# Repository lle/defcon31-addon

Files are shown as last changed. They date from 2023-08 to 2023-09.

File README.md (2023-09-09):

# DEFCON31 BLINKY BADGE-ADDON
This project recycles the same schematic and foundation code from my Snake Business Card. The main difference is that there is only a single button on the PCB that the user can interact with. In the development of this project, STM32 CubeMX and CubeIDE were used to configure and generate the HAL (hardware-abstraction-layer). Some says I'm cheating and using a code generator. I don't disagree XD.

To edit/compile/flash the code you only need to install CubeIDE. Although feel free to use any tools you like. 
You can download CubeIDE here: https://www.st.com/en/development-tools/stm32cubeide.html

## Code and Game Behavior
The badge-addon is loaded with a set of animation. The animation is selected in the main loop in "main.c". There is a switch statement that cycles between each animation. When the button is pressed, the animation is incremented to select a new one. Each animation is described in a specific .c/.h file
* anim_name.c 
* anim_random.c
* anim_swipe.c

You can add additional animation by adding a new .c/.h pair. Add an #include in main.c and call the your animation function in the switch statement.

## About the Timer16
The clock is set to 8Mhz and the timer16 counter is set to 1000 (see "tim.c"). Thus 8Mhz/1000=8Khz.
The timer runs at 8khz. It updates a new LED 8000 cycles per second. 

### Analogy
Imagine there is a cursor that is moving left to right, top to bottom. Every cycle, the cursor moves to the next LED, reads the buffer and decides if the LED should be on/off. In other words, it takes 64 cycles to update the full screen since there is 64 LEDs. Consequently, it takes 8000Hz/64LEDs = 125ms to update the full screen.

### Where is the timer handler?
The timer handler function "HAL_TIM_PeriodElapsedCallback()" is called in the file "stm32f0xx_it.c". At that location the "screen_interruptUpdate()" function is called to update the next LED.

## About LED Matrix
The chip we are using is the STM32F0. The datasheet indicates that the maximum current through a whole GPIO PORT is 30mA. The LEDs are running at 20mA with the chosen current limit resistor. Therefore, the code is set to only turn on 1 single LED at a time in order to satisfy that requirement. Since the whole screen is updated every 125ms, there is enough persistence of vision to produce a consistent animation.

The low-level function which controls the individual LEDs is located in "ledHandler.c". The function 
"matrix_setLed_on()" is used to enable an LED. It can be seen that at the beginning of it, it calls "matrix_setLed_allOff()" to disable any previous LEDs and ensure the PORT never source more than 30mA.

## About screenBuffer.c
The screenBuffer is how you interact with the LED matrix. There is 1 main fundamental fonction you need:
* screen_set_bit(row, column, state)

This is function set the state of each LEDs in the 8x8 matrix. It's either 1 (on) or 0 (off).

Additionally, there are helper functions to make animating easier:
* screen_get_bit()
* screen_fill()	
* screen_clear()

## How to Flash
Things you need:
* ST-Link - I personally use an STM32F0 Nucleo Board: [497-15096-ND](https://www.digikey.ca/en/products/detail/stmicroelectronics/NUCLEO-F072RB/5047984)
* Female Connector: [H2193-ND](https://www.digikey.ca/en/products/detail/hirose-electric-co-ltd/DF13-4P-1-25DSA/241767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)
* Male Connector: [H2181-ND](https://www.digikey.ca/en/products/detail/hirose-electric-co-ltd/DF13-4S-1-25C/241750)
* Precrimped wires x4: [H4BXG-10112-B8-ND](https://www.digikey.ca/en/products/detail/hirose-electric-co-ltd/H4BXG-10112-B8/426117)

### Instruction
* Connect the ST-Link SWD header to the PCB's programming port
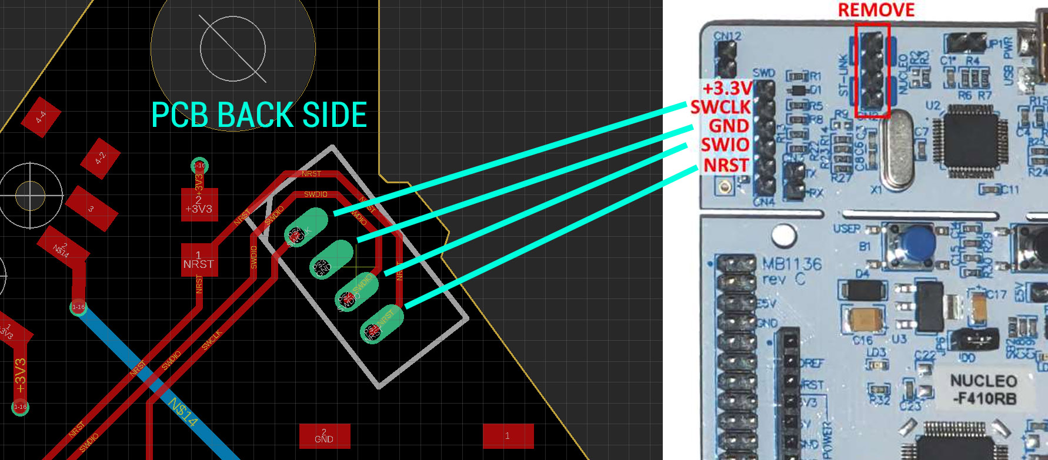
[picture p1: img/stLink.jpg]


* Compile the code in STM CubeIDE: "Project"->"Build All"
* Connect your Nucleo board to your computer
* Configure the debugger as follows: "Run" -> "Debug Configurations"
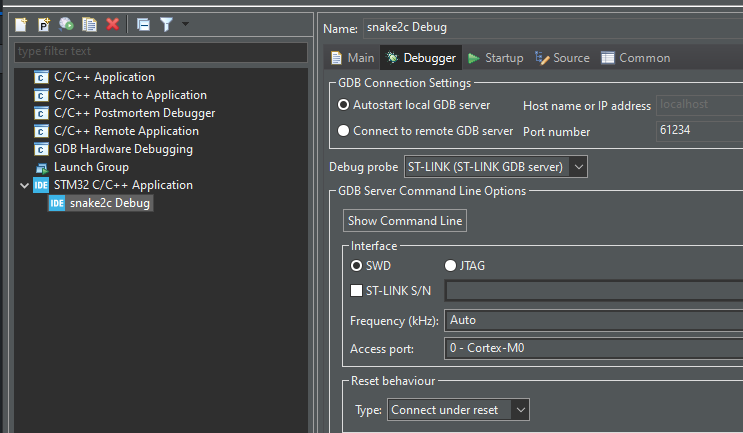
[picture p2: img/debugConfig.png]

* Flash the firmware: "Run" -> "Run"
* You will see this in the logs
```
Memory Programming ...
Opening and parsing file: ST-LINK_GDB_server_a15460.srec
  File          : ST-LINK_GDB_server_a15460.srec
  Size          : 21.34 KB 
  Address       : 0x08000000 
Erasing memory corresponding to segment 0:
Erasing internal memory sectors [0 21]
Download in Progress:
File download complete
Time elapsed during download operation: 00:00:01.454
Verifying ...
Download verified successfully 
Shutting down...
Exit.
```
* You might have to power cycle the PCB to get the firmware started the first time
* Congrats, you have flashed the addon. Happy coding.

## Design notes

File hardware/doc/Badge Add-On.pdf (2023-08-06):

Announcing…

## The Official DEF CON 31 Badge Customization Guide

(AKA the Non-Electronic Shitty Add-On Guide)
OK, but is it really a Shitty Add-On if the badge is non-electronic? Well, sort of!

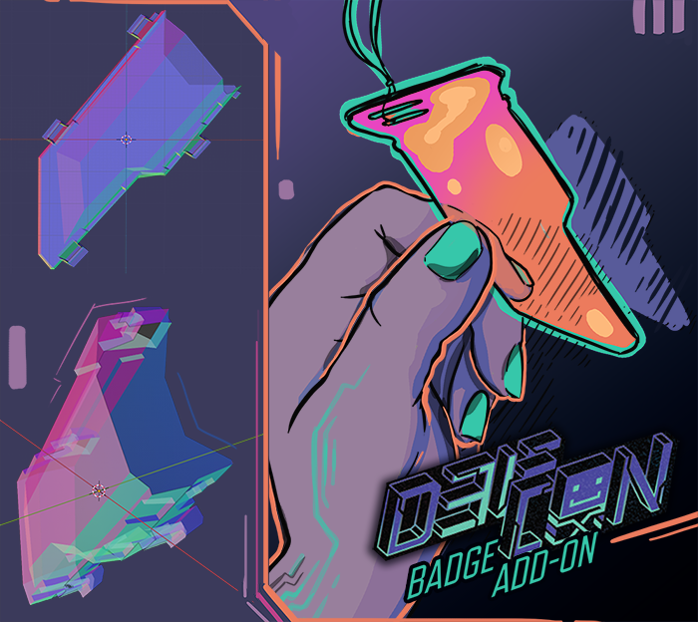
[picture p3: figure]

This year's badge is designed specifically to showcase customization. While I can't leak the whole badge, I can release the customizable portion of it.

The badge will include a small chamber, open at one end, with a transparent window facing outwards. What you put inside that chamber is entirely up to you. A PCB project, tiny snack dispenser, drawing of a cool bug... Whatever your skills and interests, you'll have some freedom to show them off.

### DETAILS:

Inside the chamber, you'll find a guide slot that runs down both sides, and is about 5mm deep. This allows an object equivalent to a thick card to slide in and out of the badge. Think PCB, laser cut acrylic, plastic card, cardboard, etc. You can totally fill the entire chamber up with pudding, and not use the guide slot at all, but for most projects, this should make things a little easier.

The inside of the chamber, from wall to wall, is 20mm at its thickest point. That means that if your project is a PCB, you'll still have space in front and back to accommodate, for example, smallish LEDs on front, and CR2032 holder and battery on back. BUT, be sure to check out the .blend file for what areas of the chamber are larger or smaller. The geometry is a little wild, and from where the card sits, the backside gives a little less room than the front.

Along the guide slot, you'll also see a couple small tab slots that should allow your project to snap in to place. I strongly recommend using a small secondary lanyard (wrist or keychain type), in addition to the tabs, to secure your project to your main lanyard, just in case. Card thicknesses will vary, and that means more wiggle for thinner materials. I can't promise that every project will stay in place while bopping around your neck at con with these specs, so please wear protection.

*Note - Inserts will be compatible with both human and inhuman badge types. Except for maybe UBER.

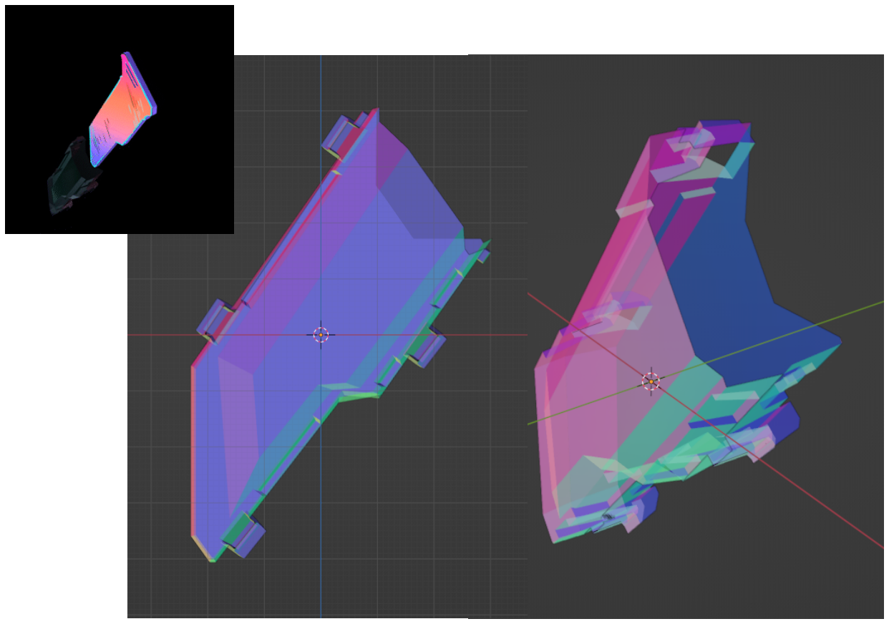
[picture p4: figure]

### BASIC MEASUREMENTS:

You’ll need to reference the .svg and .blend files for fit, but this should give you an idea of the space you’re working with.

Chamber Height: ~90mm (3.5”)
Chamber Width: ~30mm (1.2”)
Chamber Depth: ~20mm (.8”) at thickest point

Guide Slot: 5mm
Max Card Thickness for Guide Slot: 4.5mm
Min Card Thickness for Guide Slot: 1.5mm recommended (you can go thinner, but fit might get loose)

TIP: Design a small gap between measurements in the .blend file, and your project. Parts should be able to move freely without getting stuck.

A Note on Height - The chamber is wide open on one end, so you’re free to go taller, or have a ribbon cable or tentacle dangling out.

### FILES:

DC31BADGE-CARD-OUTLINE.svg
2D outline of an example insert shape, with cuts for lanyard
If you’re creating a flat object, this should be a good starting place

DC31BADGE-CHAMBER.blend
The inner geometry of the chamber, for more complex projects, so you know exactly how much space you’re working with

If you have questions, post them to the forums and I’ll do my best to answer them. Have fun, and I can’t wait to see what you create! <3
-Mar-

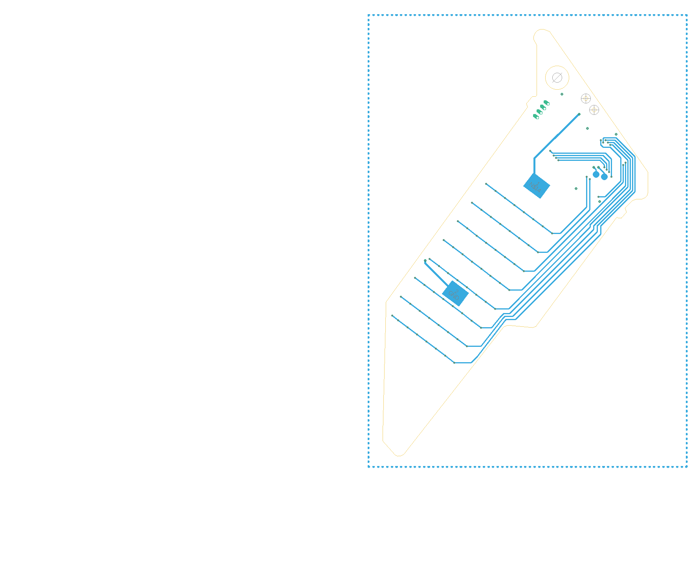
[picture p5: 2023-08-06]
hardware/gerber/pcb_bottom_copper.png

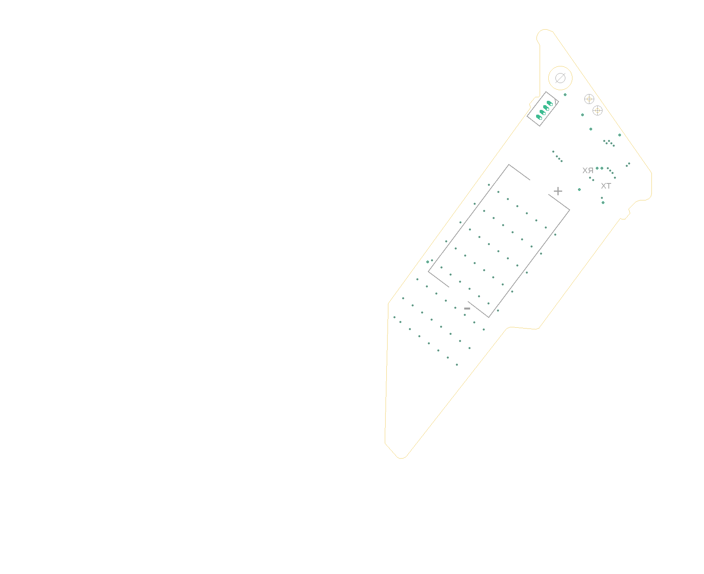
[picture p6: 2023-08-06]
hardware/gerber/pcb_bottom_silkscreen.png

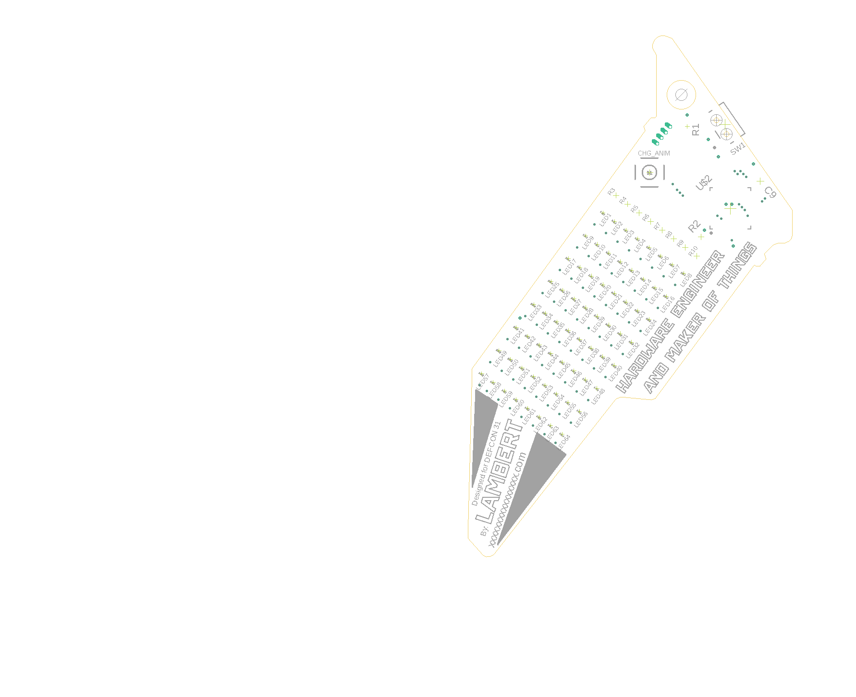
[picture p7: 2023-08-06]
hardware/gerber/pcb_top_silkscreen.png

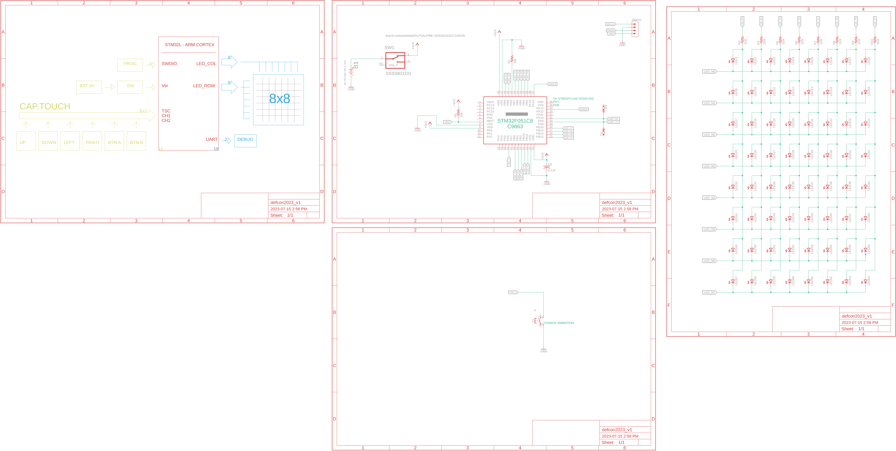
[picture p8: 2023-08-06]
hardware/gerber/schematic.png

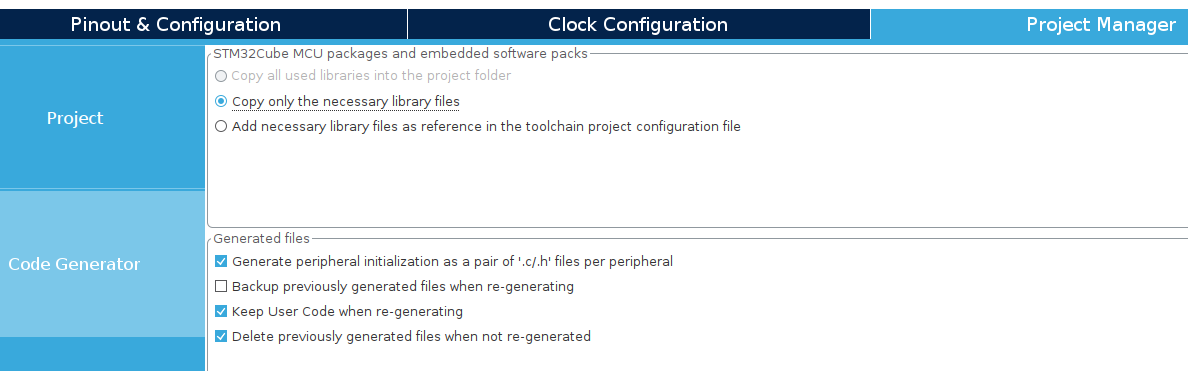
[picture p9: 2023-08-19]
img/cubeMX_codeGen.png

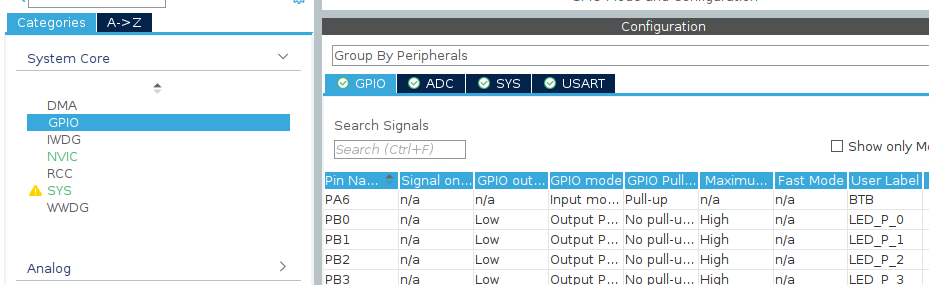
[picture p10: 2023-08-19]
img/cubeMX_gpio.png

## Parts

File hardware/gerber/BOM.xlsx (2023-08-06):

Comment | Footprint | Designator | JLCPCB ID | Digikey
 | CHIP-LED0603 | LED1 LED2 LED3 LED4 LED5 LED6 LED7 LED8 LED9 LED10 LED11 LED12 LED13 LED14 LED15 LED16 LED17 LED18 LED19 LED20 LED21 LED22 LED23 LED24 LED25 LED26 LED27 LED28 LED29 LED30 LED31 LED32 LED33 LED34 LED35 LED36 LED37 LED38 LED39 LED40 LED41 LED42 LED43 LED44 LED45 LED46 LED47 LED48 LED49 LED50 LED51 LED52 LED53 LED54 LED55 LED56 LED57 LED58 LED59 LED60 LED61 LED62 LED63 LED64 | C2286
 | TACTILE_SWITCH_SMD_5.2MM | S1 | C318884
0.1uF | C0603 | C9 | C14663
10k | R0603 | R1 R2 | C25804
110r | R0603 | R3 R4 R5 R6 R7 R8 R9 R10 | C173369
ALPS_SSSS811101ALPS_SSSS811101_0_0 | ALPS_SSSS811101_0 | SW1 | C109335
STM32L431CC | QFP50P900X900X160-48 | U$2 | C9863
Programmer Connector | 4pin 1.25mm | prog |  | H2193-ND

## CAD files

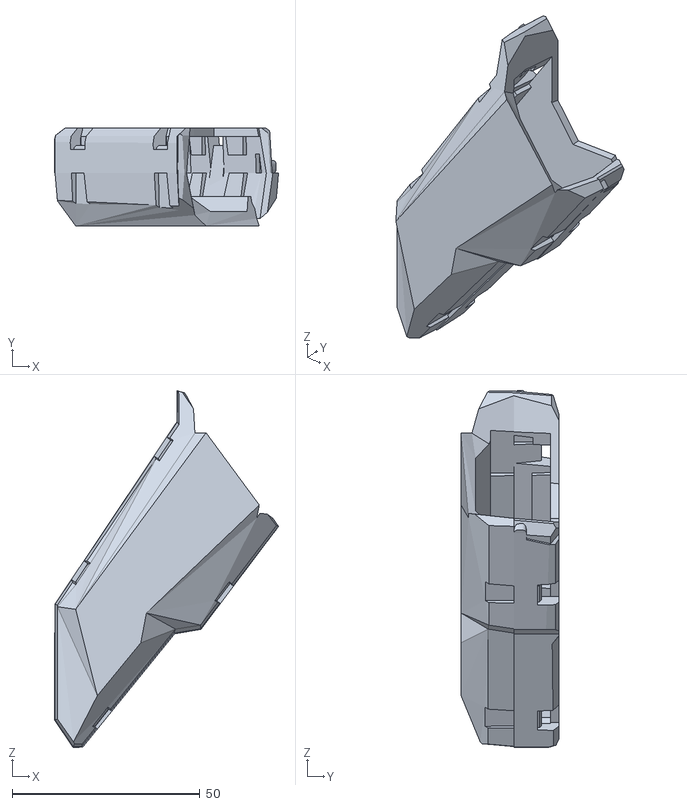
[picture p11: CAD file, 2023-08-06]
hardware/3d/chamber.stl
59.7 x 26.1 x 95.0

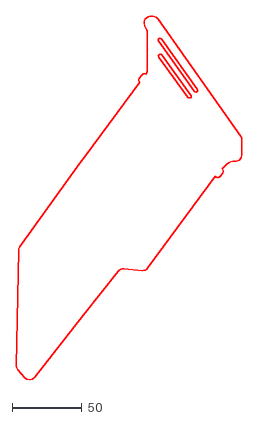
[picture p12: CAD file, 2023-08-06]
hardware/doc/DC31BADGE-CARD-OUTLINE.dxf
161.9 x 261.2

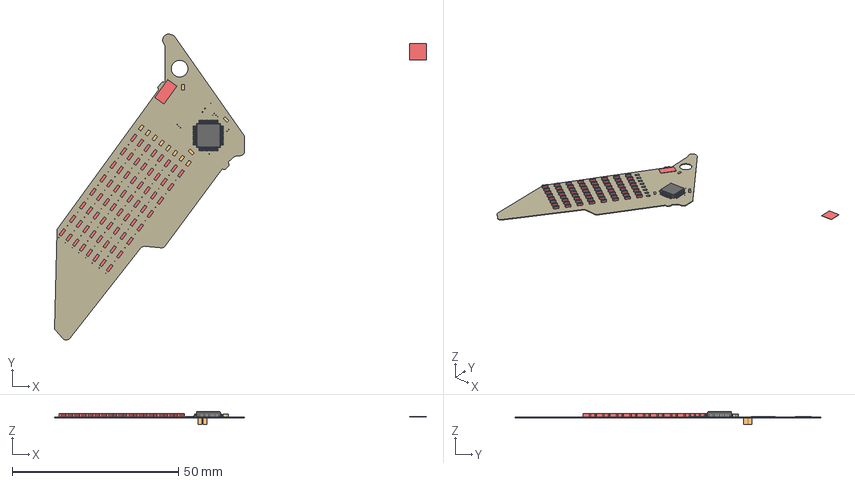
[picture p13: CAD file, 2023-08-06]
hardware/3d/defcon2023_v1.step
111.8 x 91.9 x 3.89 mm
Board
0.1uF
500r x 10
PTR1B1,27 x 2
STM32L431CC
CHIP-LED0603 x 64
4-PIN-1.25MM
TACTILE_SWITCH_SMD_5.2MM

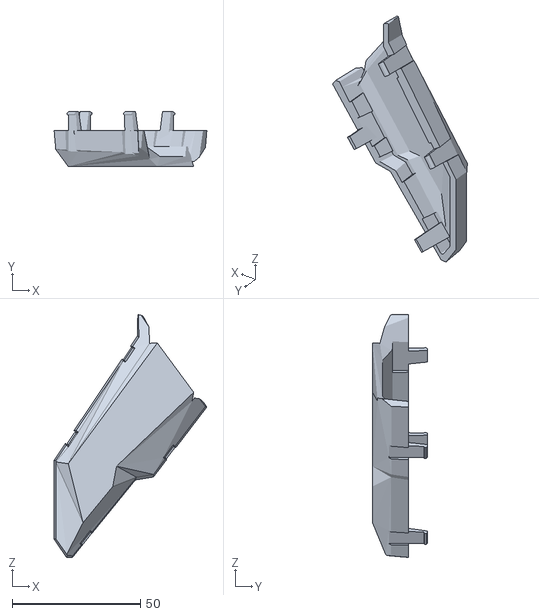
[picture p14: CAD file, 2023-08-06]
hardware/3d/chamber-PartB.stl
59.5 x 21.5 x 94.6

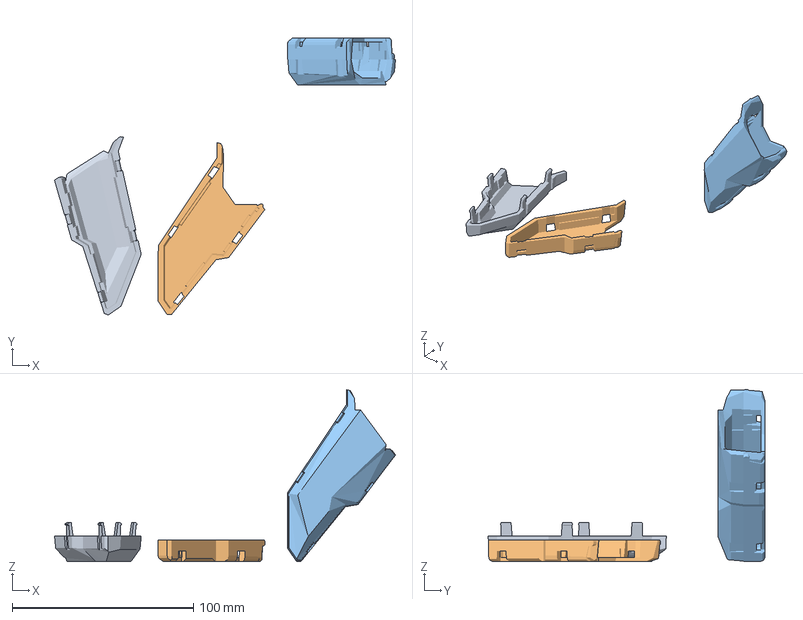
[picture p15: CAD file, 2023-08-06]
hardware/3d/Badge chamber test fit.3mf
188.4 x 153.1 x 95.0 mm
Badge chamber test fit.stl_1
Badge chamber test fit.stl_2
Badge chamber test fit.stl

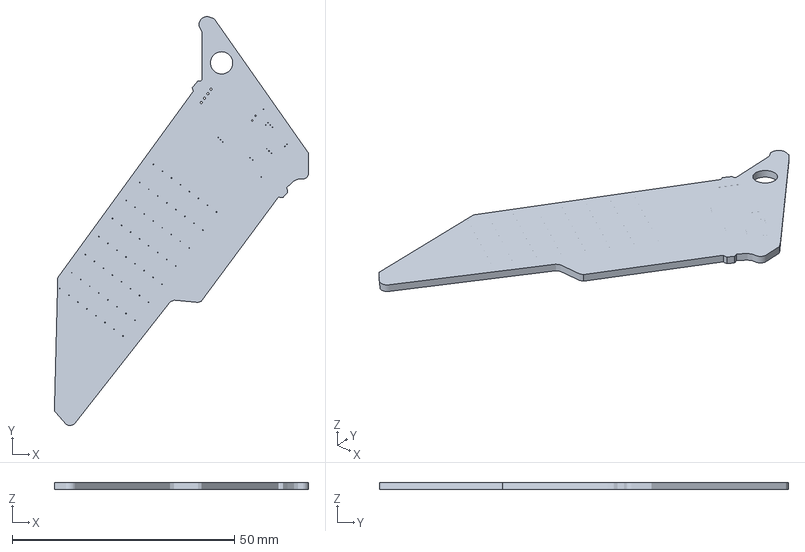
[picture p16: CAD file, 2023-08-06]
hardware/3d/pcbOnly.3mf
57.2 x 91.9 x 1.60 mm

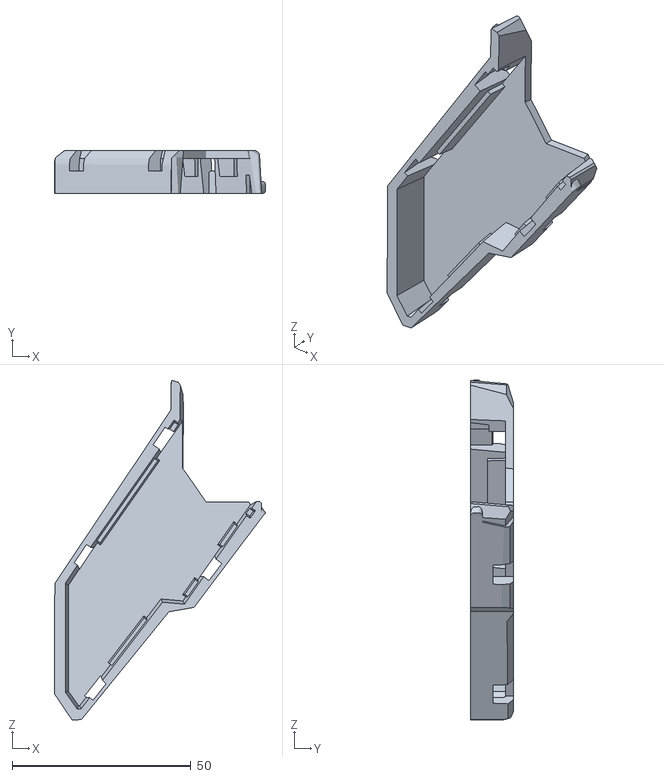
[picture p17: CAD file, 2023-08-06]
hardware/3d/chamber-PartA.stl
59.0 x 12.0 x 95.0

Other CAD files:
hardware/3d/pcbOnly.stl

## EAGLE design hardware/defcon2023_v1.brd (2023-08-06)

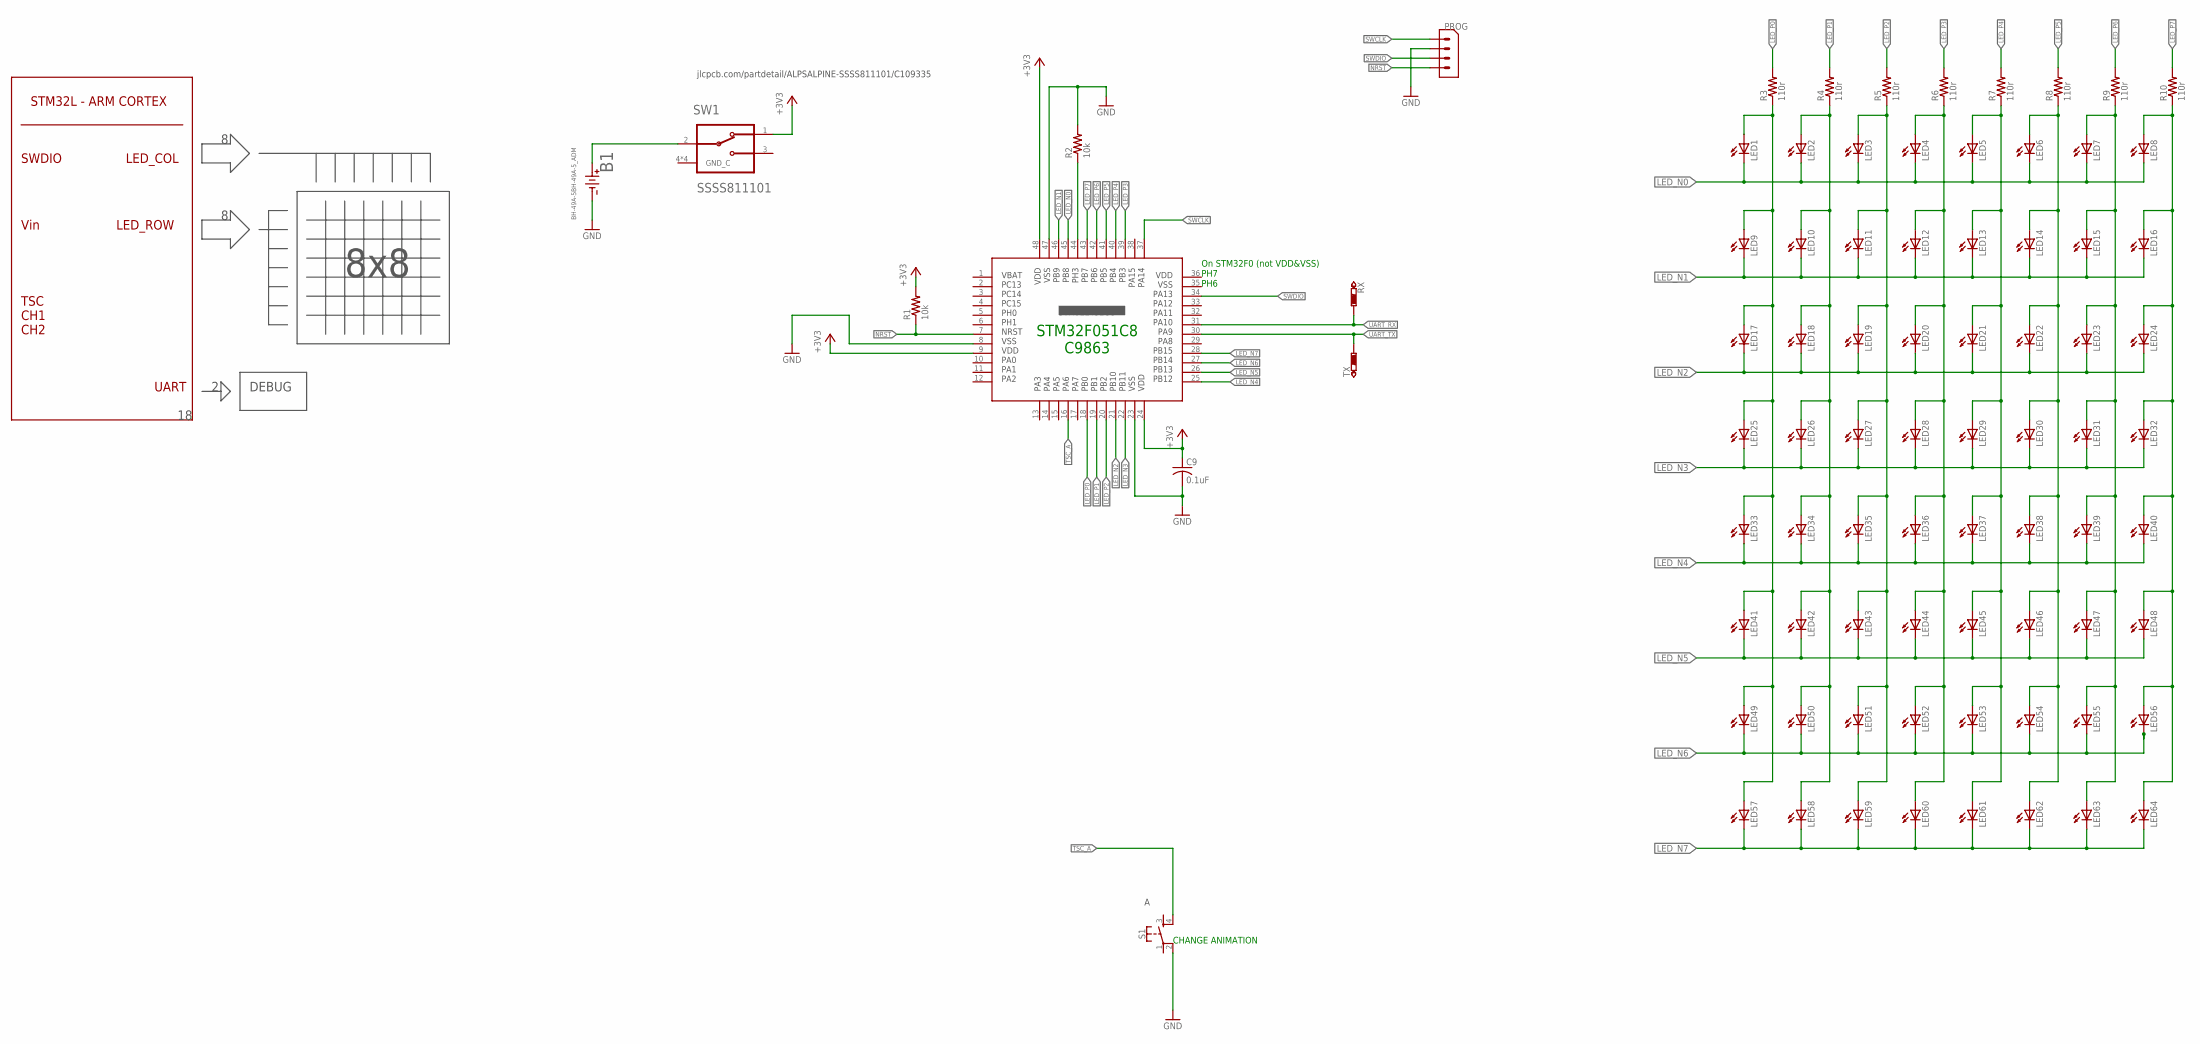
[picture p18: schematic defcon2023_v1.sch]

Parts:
B1: BH-49A-5BH-49A-5_ADM; BH-49A-5_ADM
C9: 0.1uF; C0603
LED1, LED2, LED3, LED4, LED5, LED6, LED7, LED8, LED9, LED10, LED11, LED12, LED13, LED14, LED15, LED16, LED17, LED18, LED19, LED20, LED21, LED22, LED23, LED24, LED25, LED26, LED27, LED28, LED29, LED30, LED31, LED32, LED33, LED34, LED35, LED36, LED37, LED38, LED39, LED40, LED41, LED42, LED43, LED44, LED45, LED46, LED47, LED48, LED49, LED50, LED51, LED52, LED53, LED54, LED55, LED56, LED57, LED58, LED59, LED60, LED61, LED62, LED63, LED64: LEDCHIP-LED0603; CHIP-LED0603
PROG: 4-PIN-1.25MM
R1, R2: 10k; R0603
R3, R4, R5, R6, R7, R8, R9, R10: 110r; R0603
RX: PTR1B1,27; B1,27
S1: MOMENTARY-SWITCH-SPST-2-SMD-5.2MM; TACTILE_SWITCH_SMD_5.2MM
SW1: ALPS_SSSS811101ALPS_SSSS811101_0_0; ALPS_SSSS811101_0
TX: PTR1B1,27; B1,27
U$2: STM32L431CC; QFP50P900X900X160-48

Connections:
+3V3: C9.1, R1.2, SW1.1, U$2.9, U$2.24, U$2.48
GND: B1.2, C9.2, PROG.P$3 (2), R2.2, S1.2, U$2.8, U$2.23, U$2.47
LED_N0: LED1.C, LED2.C, LED3.C, LED4.C, LED5.C, LED6.C, LED7.C, LED8.C, U$2.45
LED_N1: LED9.C, LED10.C, LED11.C, LED12.C, LED13.C, LED14.C, LED15.C, LED16.C, U$2.46
LED_N2: LED17.C, LED18.C, LED19.C, LED20.C, LED21.C, LED22.C, LED23.C, LED24.C, U$2.21
LED_N3: LED25.C, LED26.C, LED27.C, LED28.C, LED29.C, LED30.C, LED31.C, LED32.C, U$2.22
LED_N4: LED33.C, LED34.C, LED35.C, LED36.C, LED37.C, LED38.C, LED39.C, LED40.C, U$2.25
LED_N5: LED41.C, LED42.C, LED43.C, LED44.C, LED45.C, LED46.C, LED47.C, LED48.C, U$2.26
LED_N6: LED49.C, LED50.C, LED51.C, LED52.C, LED53.C, LED54.C, LED55.C, LED56.C, U$2.27
LED_N7: LED57.C, LED58.C, LED59.C, LED60.C, LED61.C, LED62.C, LED63.C, LED64.C, U$2.28
LED_P0: R3.2, U$2.18
LED_P0B: LED1.A, LED9.A, LED17.A, LED25.A, LED33.A, LED41.A, LED49.A, LED57.A, R3.1
LED_P1: R4.2, U$2.19
LED_P1B: LED2.A, LED10.A, LED18.A, LED26.A, LED34.A, LED42.A, LED50.A, LED58.A, R4.1
LED_P2: R5.2, U$2.20
LED_P2B: LED3.A, LED11.A, LED19.A, LED27.A, LED35.A, LED43.A, LED51.A, LED59.A, R5.1
LED_P3: R6.2, U$2.39
LED_P3B: LED4.A, LED12.A, LED20.A, LED28.A, LED36.A, LED44.A, LED52.A, LED60.A, R6.1
LED_P4: R7.2, U$2.40
LED_P4B: LED5.A, LED13.A, LED21.A, LED29.A, LED37.A, LED45.A, LED53.A, LED61.A, R7.1
LED_P5: R8.2, U$2.41
LED_P5B: LED6.A, LED14.A, LED22.A, LED30.A, LED38.A, LED46.A, LED54.A, LED62.A, R8.1
LED_P6: R9.2, U$2.42
LED_P6B: LED7.A, LED15.A, LED23.A, LED31.A, LED39.A, LED47.A, LED55.A, LED63.A, R9.1
LED_P7: R10.2, U$2.43
LED_P7B: LED8.A, LED16.A, LED24.A, LED32.A, LED40.A, LED48.A, LED56.A, LED64.A, R10.1
unnamed: R2.1, U$2.44
unnamed: B1.1, SW1.2 (C)
NRST: PROG.P$1 (4), R1.1, U$2.7
SWCLK: PROG.P$4 (1), U$2.37
SWDIO: PROG.P$2 (3), U$2.34
TSC_A: S1.4, U$2.16
UART_RX: RX.TP, U$2.31
UART_TX: TX.TP, U$2.30

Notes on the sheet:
SWDIO
Vin
LED_COL
LED_ROW
TSC CH1 CH2
STM32L - ARM CORTEX
DEBUG
UART
8x8
jlcpcb.com/partdetail/ALPSALPINE-SSSS811101/C109335
STM32F051C8 C9863
On STM32F0 (not VDD&VSS) PH7 PH6
CHANGE ANIMATION

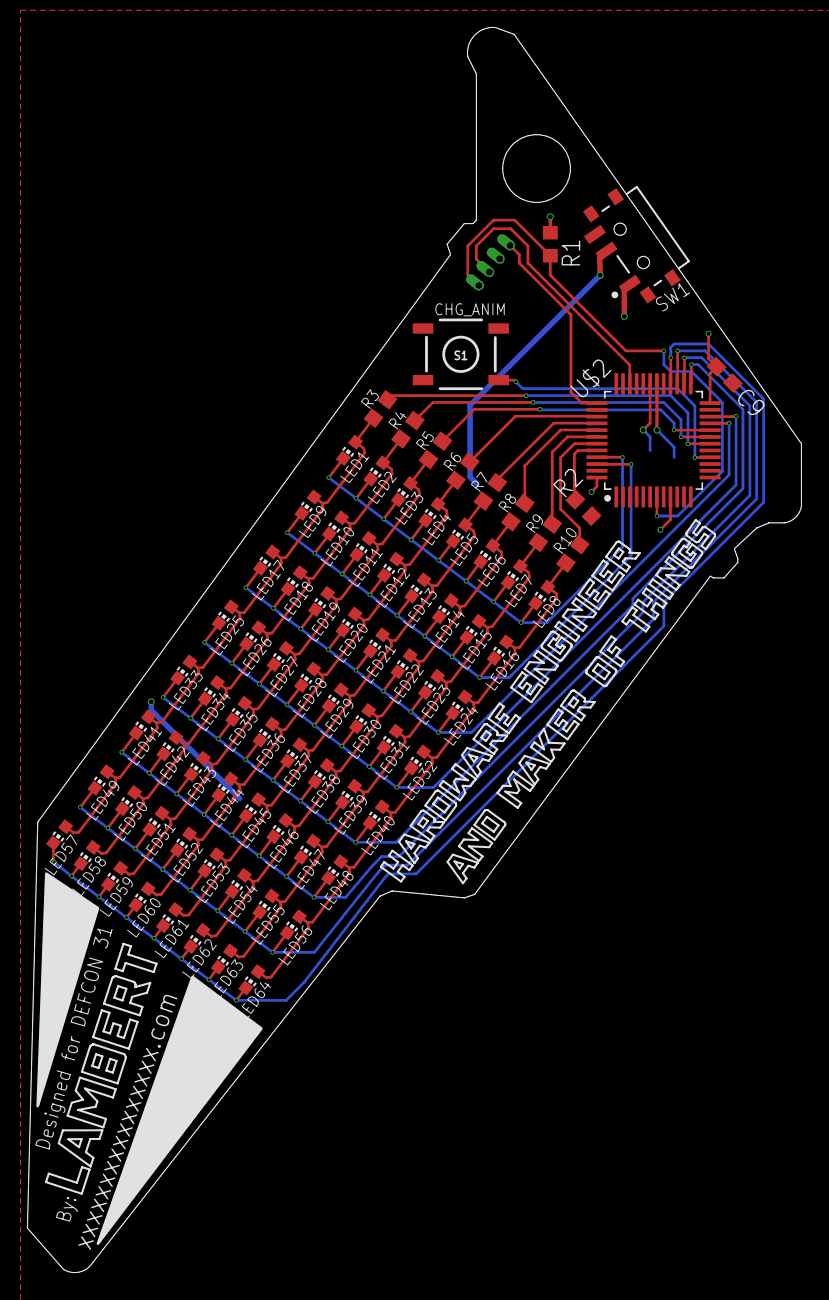
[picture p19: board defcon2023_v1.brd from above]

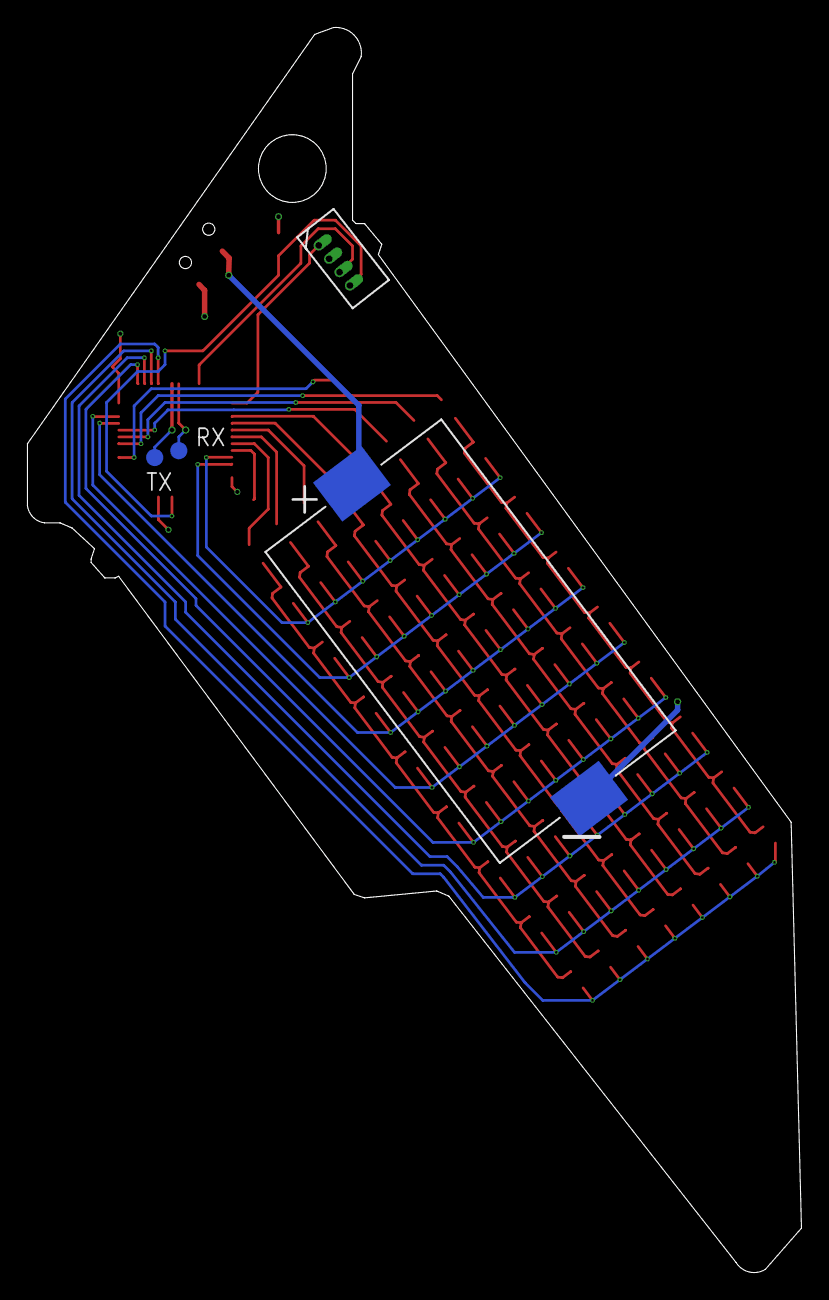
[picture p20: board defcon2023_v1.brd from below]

Board: 2 copper layers, 57.1 x 91.9 mm, 82 parts (4 on the bottom side), 34 nets.

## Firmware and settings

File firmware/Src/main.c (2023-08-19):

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
/* Includes ------------------------------------------------------------------*/
#include "main.h"
#include "adc.h"
#include "tim.h"
#include "usart.h"
#include "gpio.h"

/* USER CODE BEGIN Includes */


#include "screenBuffer.h"
#include "ascii_letter.h"
#include "anim_random.h"
#include "anim_swipe.h"
#include "anim_name.h"
#include "anim_ball.h"
#include "anim_life.h"


/* USER CODE END Includes */

/* USER CODE BEGIN PD */

#define MAX_ANIM_ID 10
#define DELAY_PER_LETTER 500
uint8_t currentAnimation = 0;

/* USER CODE END PD */


void SystemClock_Config(void);
/**
  * @brief  The application entry point.
  * @retval int
  */
int main(void)
{
  /* MCU Configuration--------------------------------------------------------*/

  /* Reset of all peripherals, Initializes the Flash interface and the Systick. */
  HAL_Init();

  /* Configure the system clock */
  SystemClock_Config();

  /* Initialize all configured peripherals */
  MX_GPIO_Init();
  MX_USART1_UART_Init();
  MX_TIM16_Init();
  MX_ADC_Init();
  /* USER CODE BEGIN 2 */



  //Generate seed from floating ADC pin
  HAL_ADC_Start(&hadc);
  uint32_t seed = 0;
  uint32_t currentVal = 0;
  for(int i=0; i<10; i++)
  {
	  HAL_ADC_PollForConversion(&hadc, 0xFF);
	  currentVal = HAL_ADC_GetValue(&hadc);
	  seed = seed + currentVal;
	  HAL_Delay(2);
  }
  srand(seed);	//input seed into sRand

  //start timer for screen refresh
  HAL_TIM_Base_Start_IT(&htim16);

  uint32_t schedulerTimestamp_updateName = 0;

  // Initiate matrix for conway
  anim_life_setup();

  /* USER CODE END 2 */

  /* Infinite loop */
  /* USER CODE BEGIN WHILE */
  while (1)
  {
    /* USER CODE END WHILE */

    /* USER CODE BEGIN 3 */


	if( HAL_GPIO_ReadPin(BTB_GPIO_Port, BTB_Pin) == GPIO_PIN_RESET )
	{
		currentAnimation++;
		if(currentAnimation == MAX_ANIM_ID)
			currentAnimation = 0;

		//HAL_Delay(100);
		while(HAL_GPIO_ReadPin(BTB_GPIO_Port, BTB_Pin) == GPIO_PIN_RESET)
		{
			screen_show_letter((currentAnimation < 9)?(ASCII_ONE + currentAnimation):(ASCII_LOWER_A + currentAnimation - 9));
			HAL_Delay(100);
		}
	}


	switch(currentAnimation)
	{
		 case 0:
			 anim_random_run();
			 break;
		 case 1:
			 if(HAL_GetTick() - schedulerTimestamp_updateName > DELAY_PER_LETTER)
			 {
				 schedulerTimestamp_updateName = HAL_GetTick();
				 anim_name_word("DEFCON31! ");
			 }
			 break;
		 case 2:
			 anim_horizontal_run();
			 break;
		 case 3:
			 anim_vertical_run();
			 break;
		 case 4:
			 anim_diagonal_run();
			 break;
		 case 5:
			 anim_rotate_run();
			 break;
		 case 6:
			 if(HAL_GetTick() - schedulerTimestamp_updateName > DELAY_PER_LETTER)
			 {
				 schedulerTimestamp_updateName = HAL_GetTick();
				 anim_name_word("RAWR! ^.^ ");
			 }
			 break;
		 case 7:
			 anim_swipeAll_run();
			 break;
		 case 8:
			 anim_ball_run();
			 break;
		 case 9:
			 anim_life_run();
			 break;
		 default:
			 screen_fill(); HAL_Delay(10);
			 screen_clear(); HAL_Delay(10);
			 break;

	}


  }
  /* USER CODE END 3 */
}

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


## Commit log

2023-08-06 Add hardware files
    [BOM.xlsx, Badge chamber test fit.3mf, Badge chamber test fit.stl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]
2023-08-06 added schematic+pcb PNG
2023-08-08 Added conway's game of life from github.com/mtagius/game-of-life-8x8-arduino-matrix
2023-08-19 restructured folders
    [BOM.xlsx, Badge chamber test fit.3mf, Badge chamber test fit.stl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]
2023-08-19 Updated to latest STM32 HAL

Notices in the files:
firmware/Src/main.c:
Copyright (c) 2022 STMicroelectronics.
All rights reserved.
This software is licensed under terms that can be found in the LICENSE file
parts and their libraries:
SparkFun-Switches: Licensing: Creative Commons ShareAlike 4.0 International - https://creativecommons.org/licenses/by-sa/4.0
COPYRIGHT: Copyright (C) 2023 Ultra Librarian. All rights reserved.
